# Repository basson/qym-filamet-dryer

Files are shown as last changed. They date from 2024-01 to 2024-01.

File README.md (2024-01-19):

# qym-filamnet-dryer

DIY filament dryer

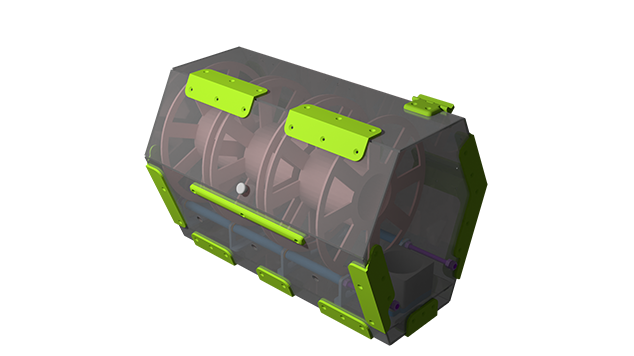
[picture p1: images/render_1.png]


Сушилка на 3 катушки, с возможностью печатать сразу из сушилки.

Помещаться должны самые большие катушки размеры которых я нашел.

Максимальная ширина катушки 98мм максимальный диаметр катушки 215мм.

Проект находится в стадии разработки.

Вся разработка ведётся на стримах.

Следить за проектом можно на моем канале YouTube:

https://www.youtube.com/playlist?list=PLECrWHz_TG886tEzgreLgq92PoEziWuON

# Планируемый функционал:

* Контроль температуры и влажности.
* Таймеры для сушки.
* Разные алгоритмы сушики пластика.
* Интеграция в klipper для управления из него.
* Для владельцев Flying Bear GHost 6 есть возможность установки сушилки вторым этажом прям на колпак принтера. (Колпак пилится одновременно с сушилкой и скоро тоже появится у меняв репозиториях)

---

**Что имеем сейчас:**

В папках stl, cad, draft чертежи для раскроя панелей на CO2 лазере, модели для печатных деталей и step фалы если кто-то решит что, то поправить.

Что будем делать на стримах:

* Проектировать плату в Kicad (схема уже накидана).
* Писать прошивку для управления сушилкой.
* Делать интеграцию в Klipper.
* Печать всех деталей для новой версии сборка и тесты сушилки.

---

**Подписывайся на мой youtube канал я там стараюсь вести регулярные стримы по всем своим проектам!!**

YouTube Transalations - https://www.youtube.com/@basson_xvi/streams

Thingiverse - https://www.thingiverse.com/thing:6427349

Printables - https://www.printables.com/model/716319-flying-bear-ghost-6-slim-skirt-for-electronics-pla

(https://www.buymeacoffee.com/basson)

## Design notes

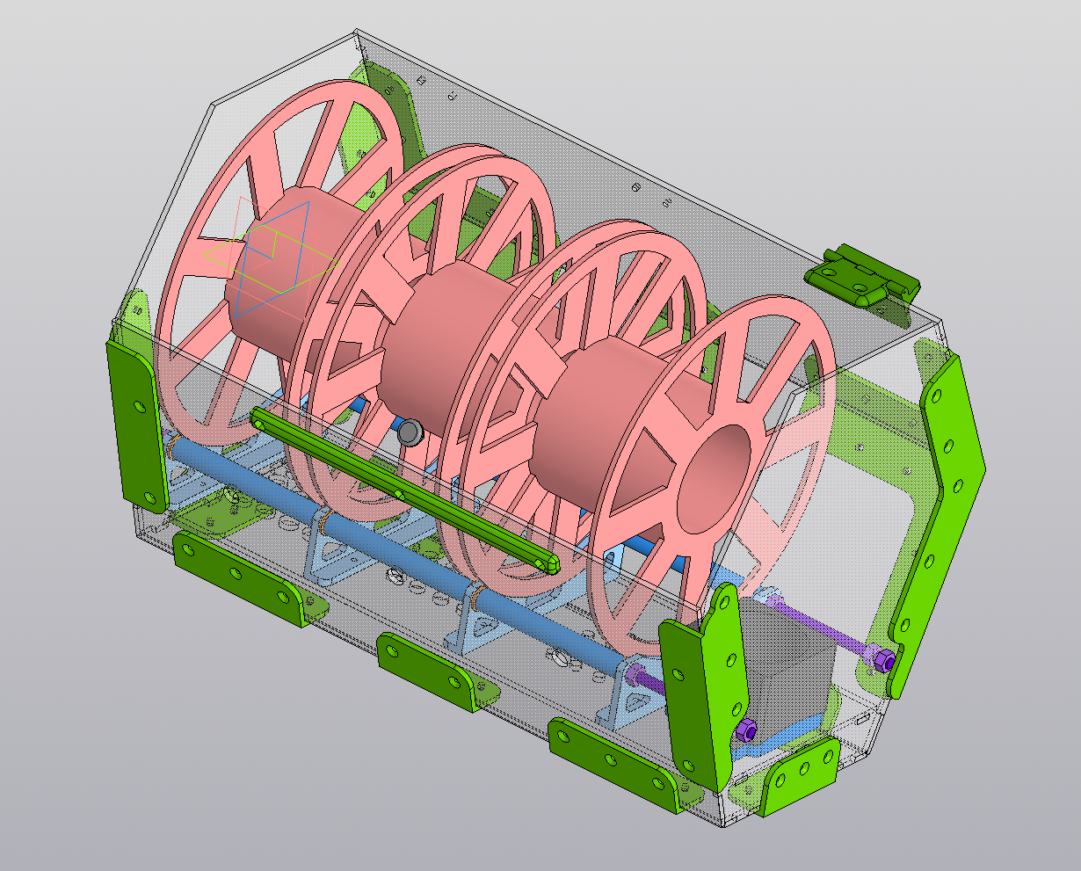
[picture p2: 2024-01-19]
images/screen_2.png

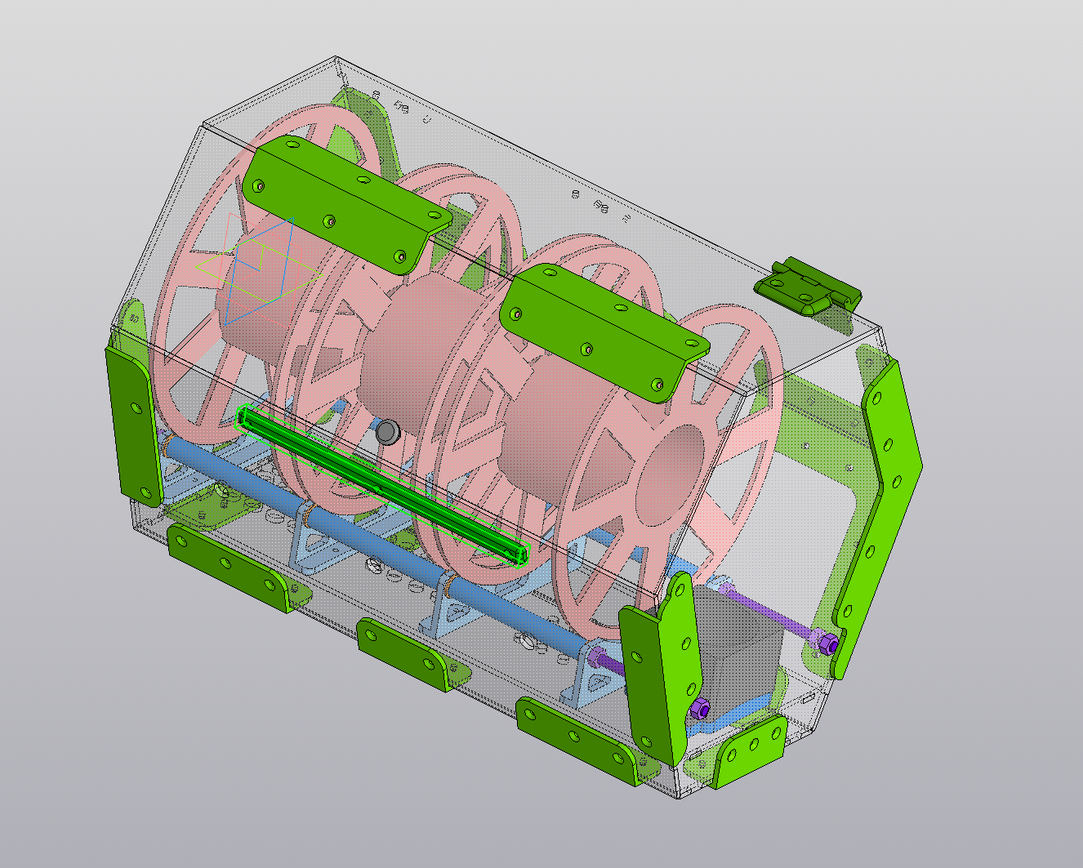
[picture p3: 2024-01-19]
images/screen_1.png

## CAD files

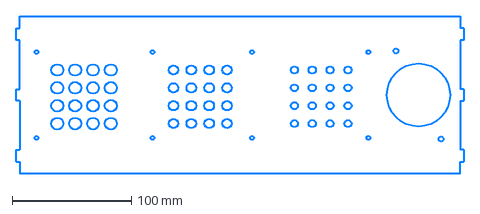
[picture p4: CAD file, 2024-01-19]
draft/holder_floor.dxf
376.0 x 132.0 mm

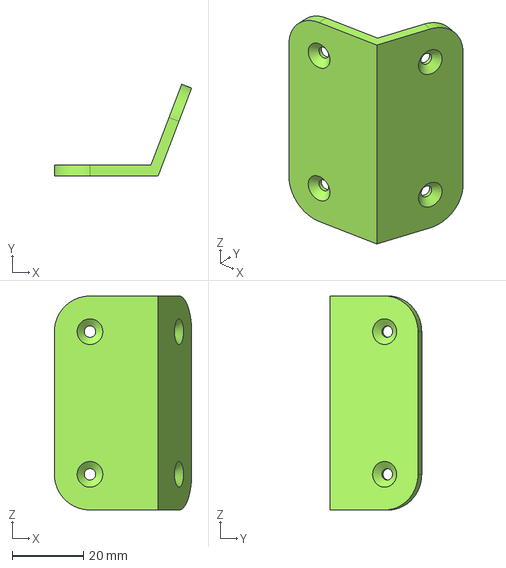
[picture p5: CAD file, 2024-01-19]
cad/Corner_bottom_front_centered.stp
38.5 x 25.7 x 60.0 mm

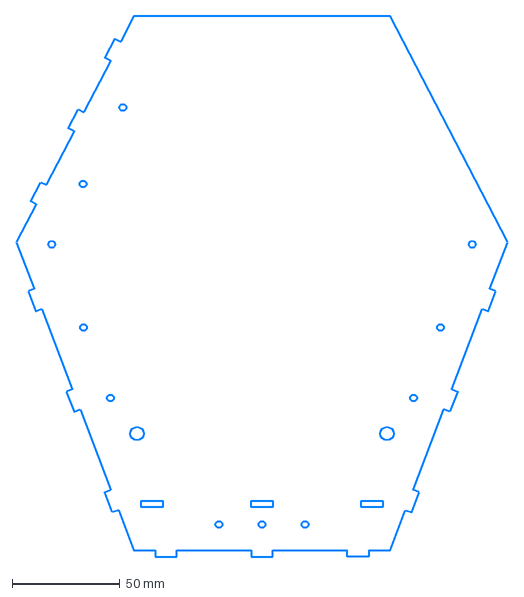
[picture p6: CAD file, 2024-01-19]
draft/side_wall.dxf
228.0 x 251.0 mm

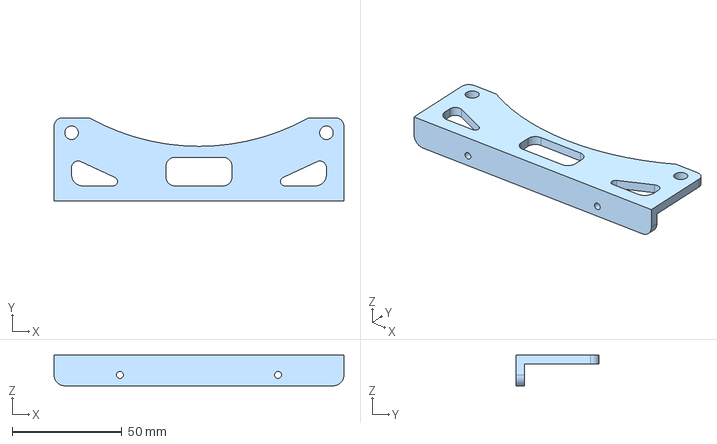
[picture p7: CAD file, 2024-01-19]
cad/holder.stp
132.0 x 38.0 x 14.0 mm

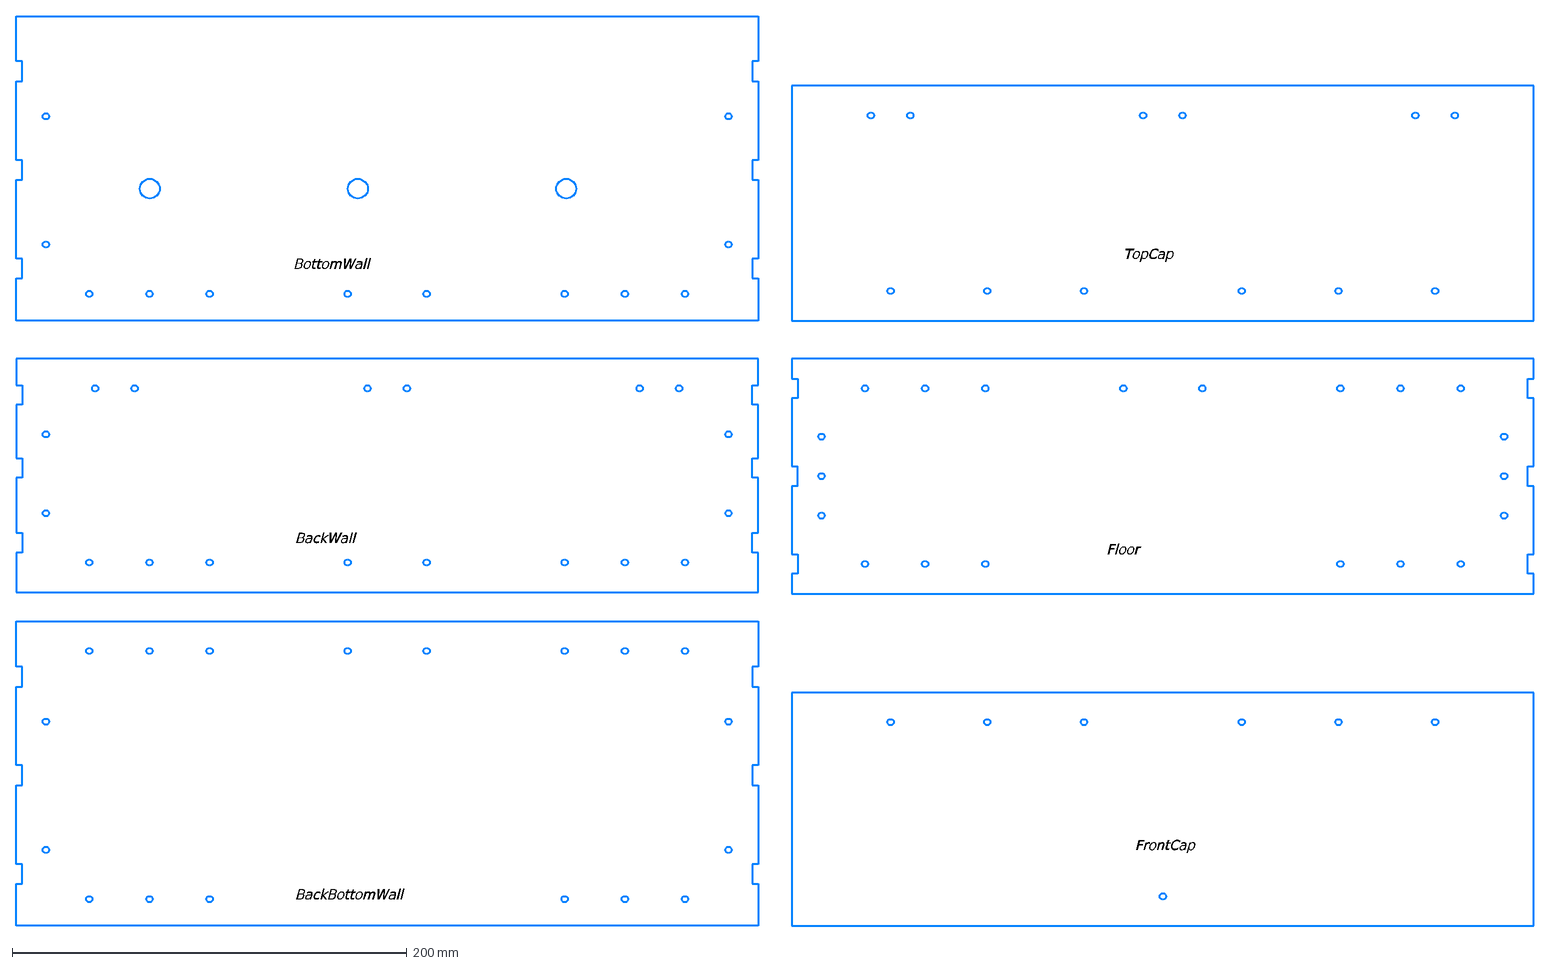
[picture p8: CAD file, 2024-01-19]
draft/all_walls.dxf
BackBottomWall
BackWall
BottomWall
Floor
FrontCap
TopCap

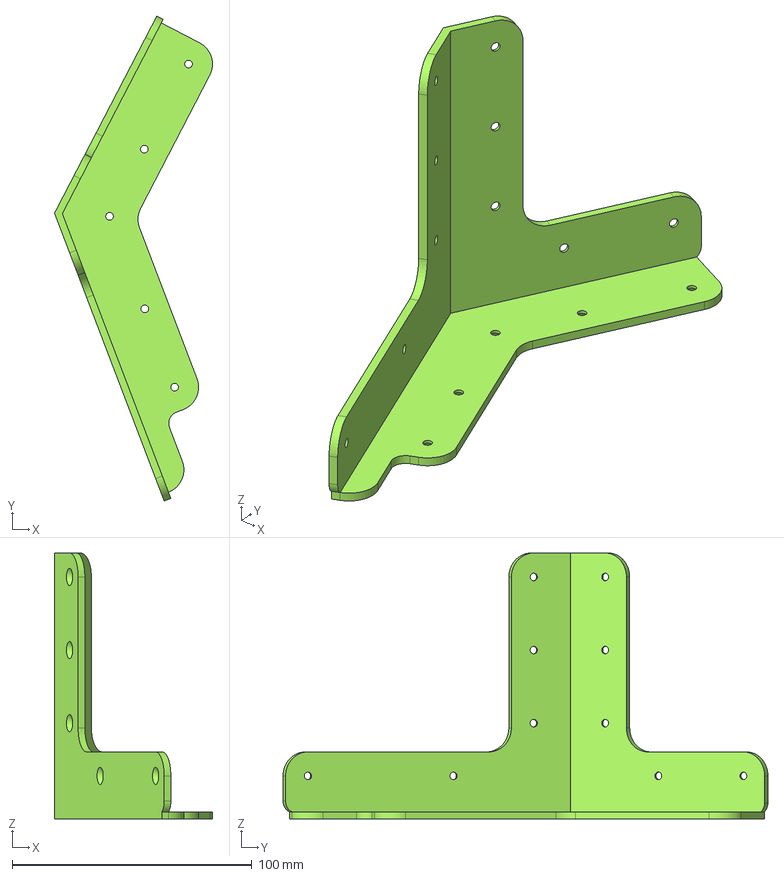
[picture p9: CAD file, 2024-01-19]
cad/Corner_back_side.stp
66.0 x 202.4 x 111.0 mm

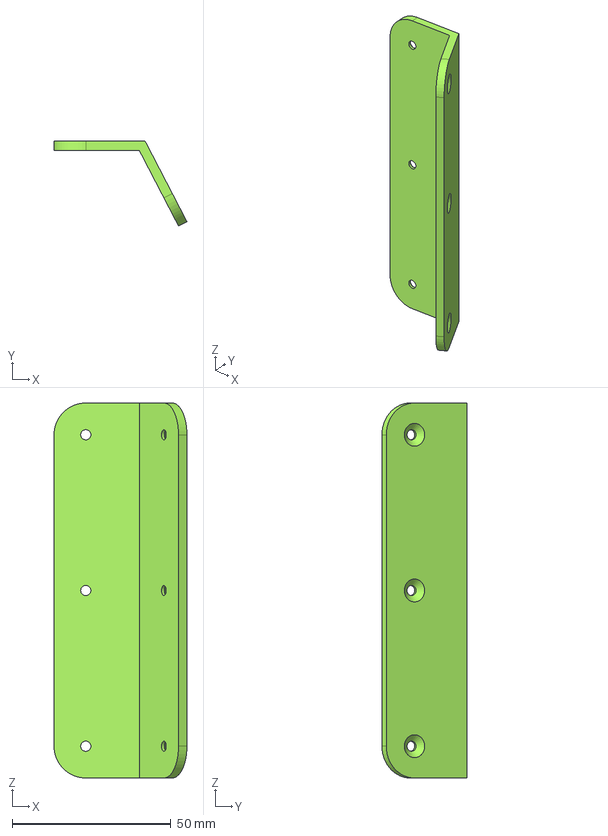
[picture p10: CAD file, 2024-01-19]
cad/Corner_cap.stp
41.8 x 26.8 x 118.0 mm

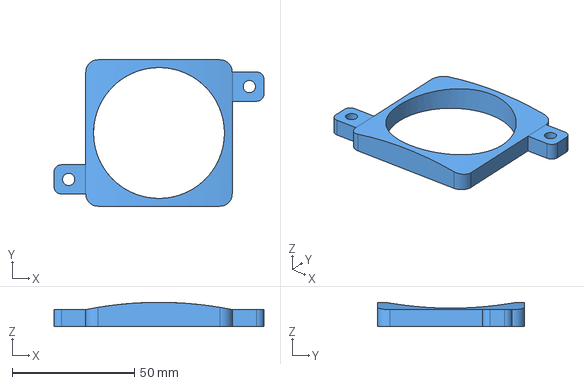
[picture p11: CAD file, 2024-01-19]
cad/Air_Conductor_2.stp
86.0 x 60.0 x 10.00 mm

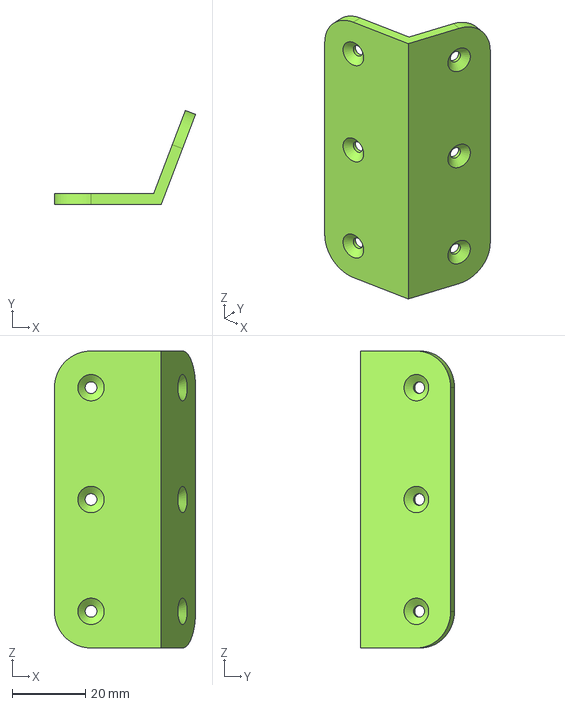
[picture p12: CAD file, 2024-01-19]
cad/Corner_bottop_front.stp
38.5 x 25.7 x 81.0 mm

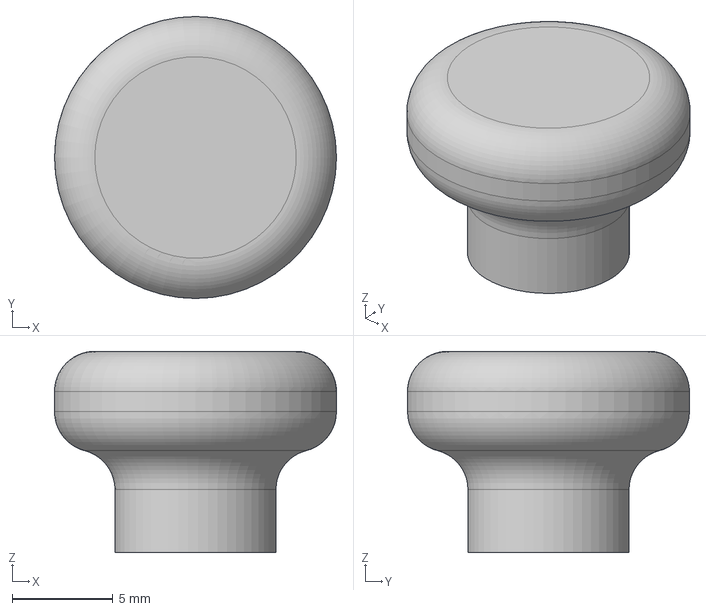
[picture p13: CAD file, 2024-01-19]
cad/Ruchka.stp
14.0 x 14.0 x 10.0 mm

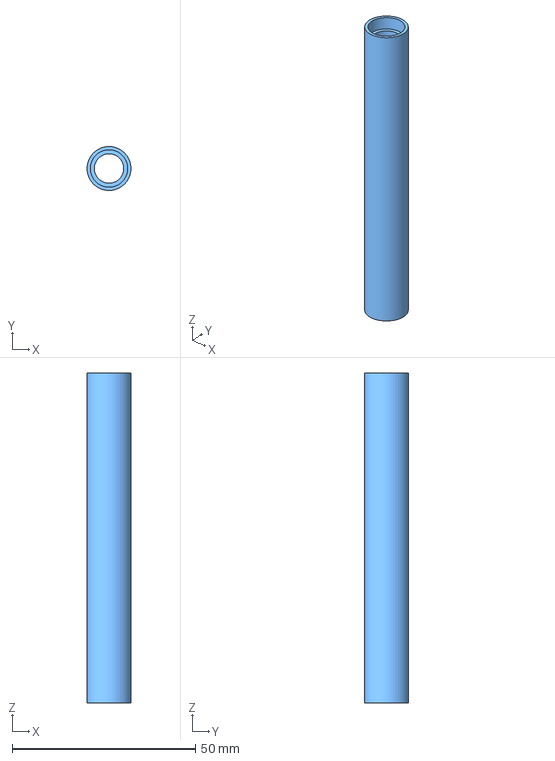
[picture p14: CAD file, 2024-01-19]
cad/roller.stp
12.0 x 12.0 x 90.0 mm

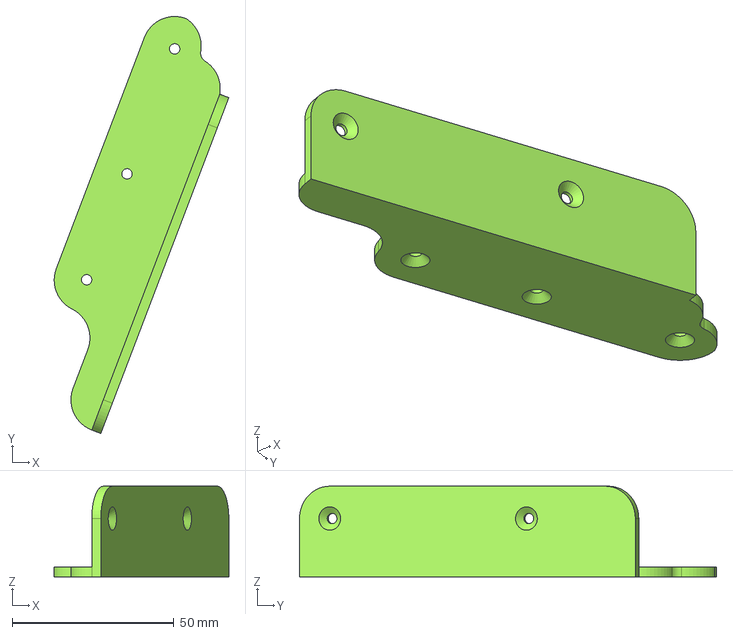
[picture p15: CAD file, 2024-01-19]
cad/Corner_front_side.stp
53.9 x 128.8 x 28.0 mm

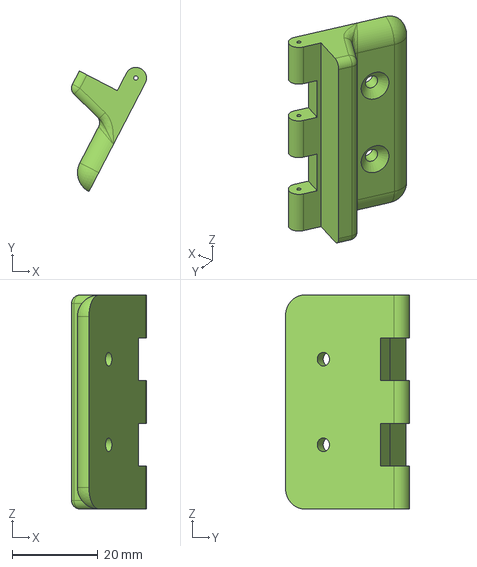
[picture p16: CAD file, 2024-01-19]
cad/Hinge_wall.stp
17.6 x 29.0 x 50.0 mm

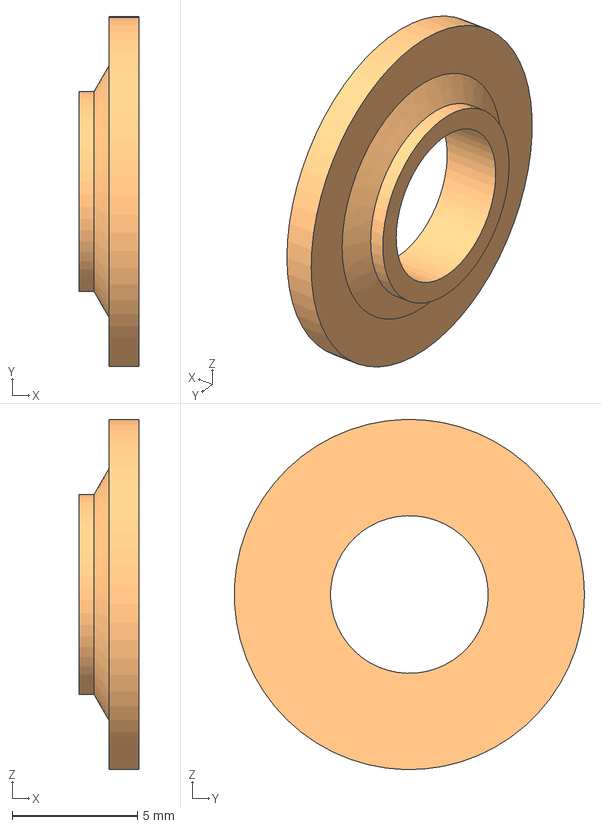
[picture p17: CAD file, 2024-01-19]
cad/Spacer_D14x8x6.3_W2.4.stp
2.40 x 14.0 x 14.0 mm

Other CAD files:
cad/dry.stp
cad/Streang_Beam_Bottom.stp
cad/Hinge_cover.stp
cad/Corner_back_centered.stp
cad/Corner_bottom_side.stp
cad/fitting_nut.stp
stl/Air_Conductor_2.stl
stl/Corner_back_centered.stl
stl/Corner_back_side.stl
stl/Corner_bottom_front_centered.stl
stl/Corner_bottom_side.stl
stl/Corner_bottop_front.stl
stl/Corner_cap.stl
stl/Corner_front_side.stl
stl/Hinge_cover.stl
stl/Hinge_wall.stl
stl/Ruchka.stl
stl/Spacer_D14x8x6.3_W2.4.stl
stl/Streang_Beam_Bottom.stl
stl/fitting_nut.stl
stl/holder.stl
stl/roller.stl

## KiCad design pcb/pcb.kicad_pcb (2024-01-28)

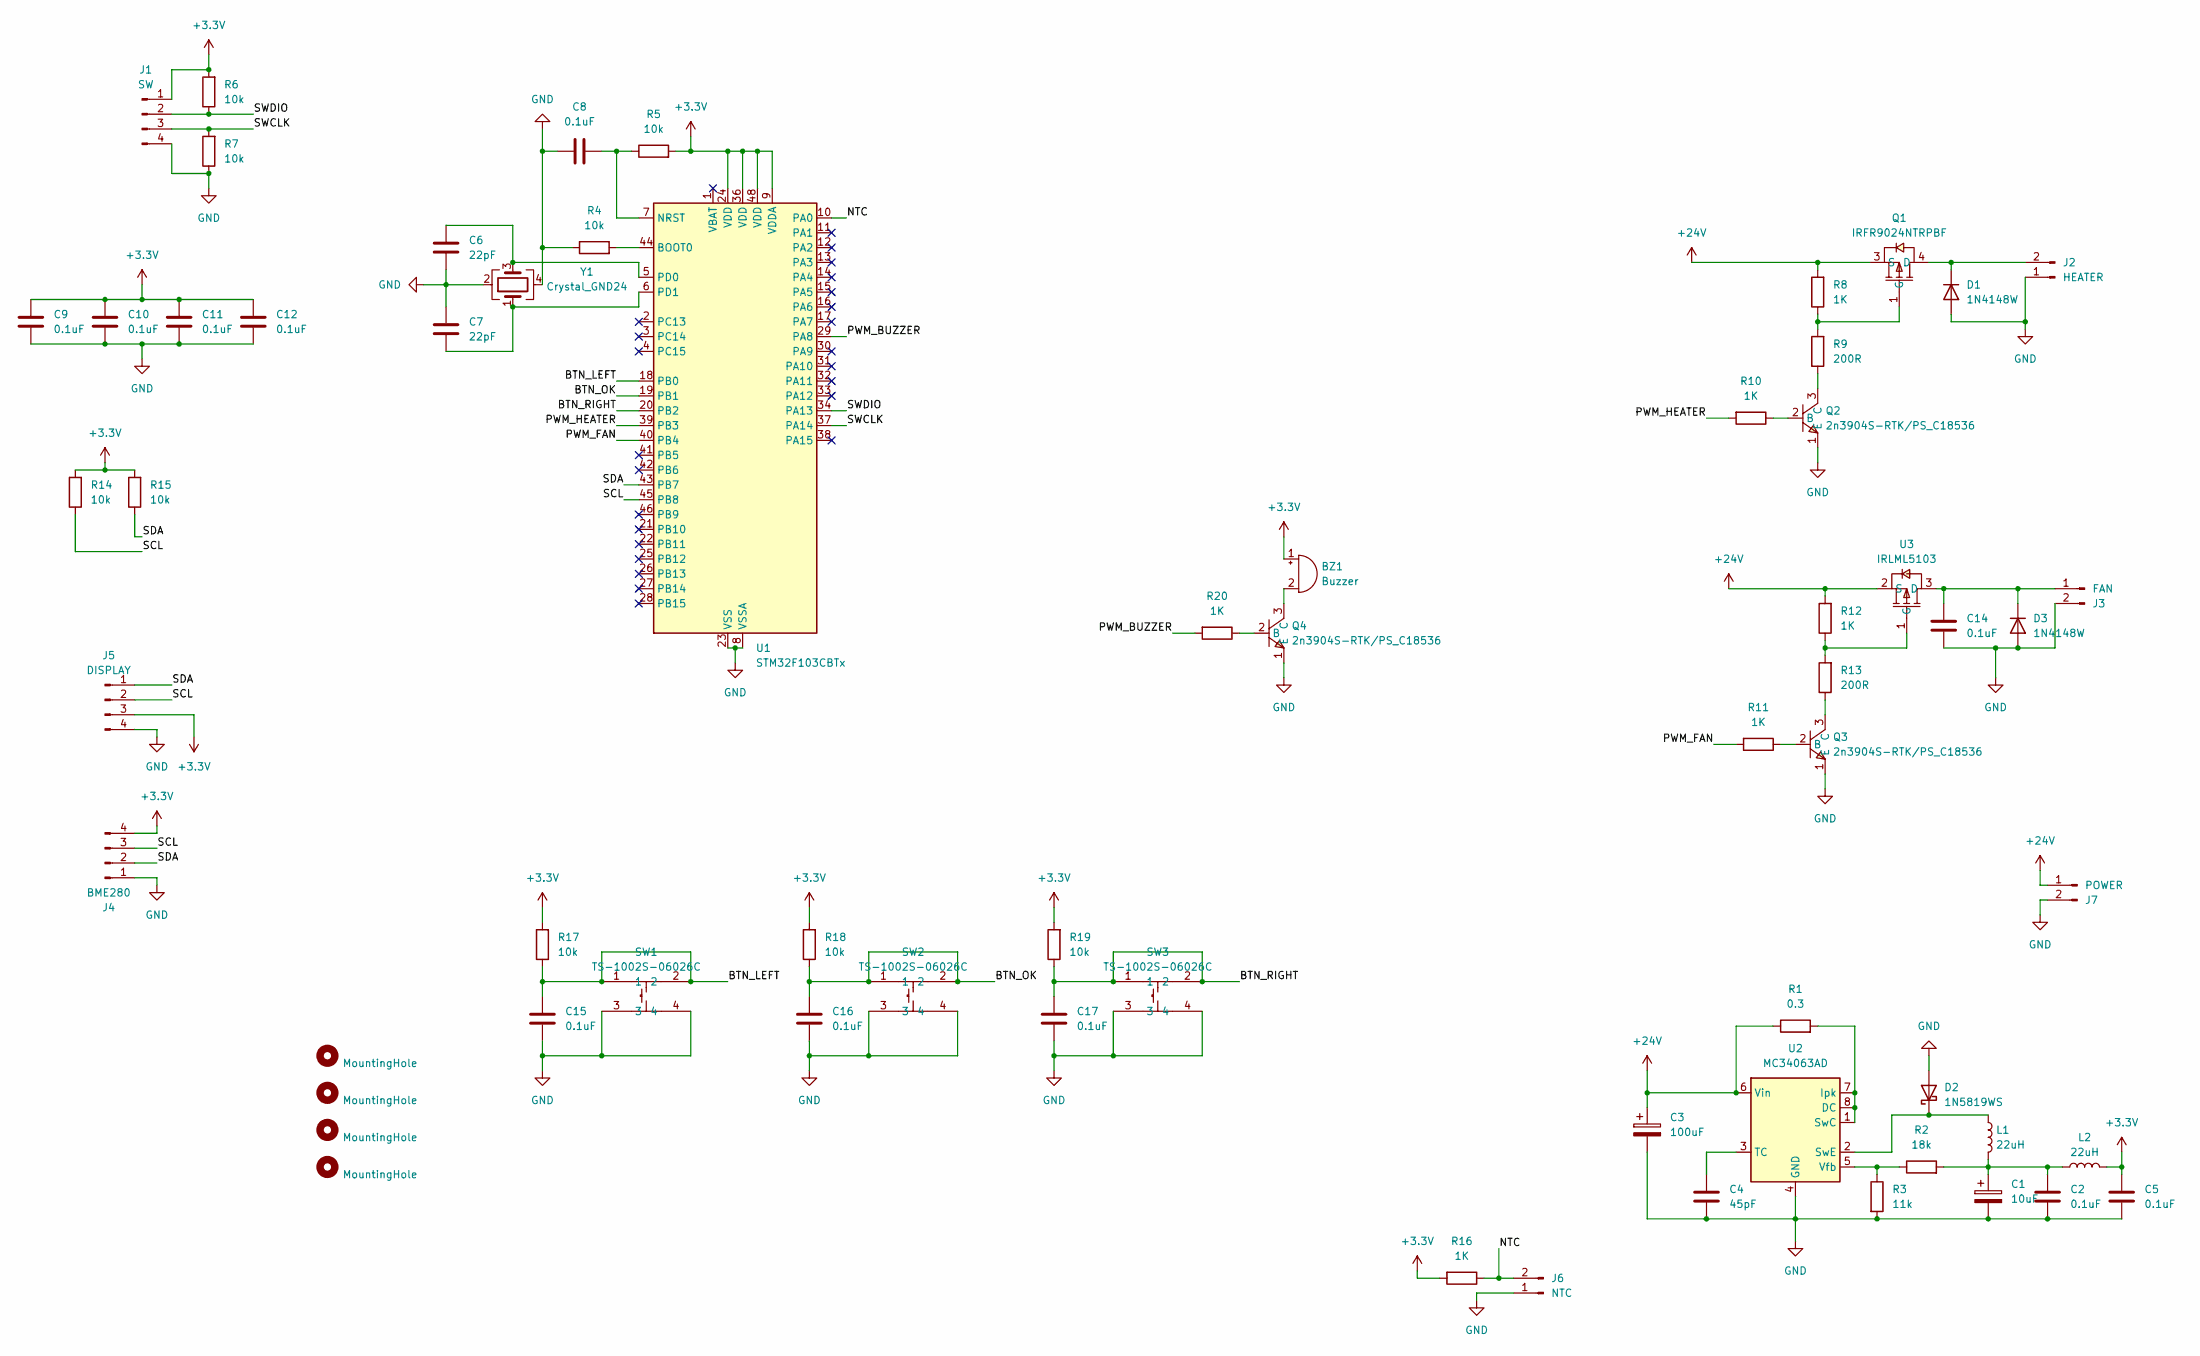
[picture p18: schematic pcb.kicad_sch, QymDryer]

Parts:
BZ1: Buzzer; Buzzer_12x9.5RM7.6
C1: 10uF; CP_Radial_D5.0mm_P2.50mm
C2, C5, C8, C9, C10, C11, C12, C14, C15, C16, C17: 0.1uF; C_1206_3216Metric_Pad1.33x1.80mm_HandSolder
C3: 100uF; CP_Radial_D8.0mm_P5.00mm
C4: 45pF; C_1206_3216Metric_Pad1.33x1.80mm_HandSolder
C6, C7: 22pF; C_1206_3216Metric_Pad1.33x1.80mm_HandSolder
D1, D3: 1N4148W; D_SOD-123
D2: 1N5819WS; D_2114_3652Metric_Pad1.85x3.75mm_HandSolder
H1, H2, H3, H4: MountingHole; MountingHole_3.2mm_M3_DIN965_Pad
J1: SW; PinHeader_1x04_P2.54mm_Vertical
J2: HEATER; TerminalBlock_Phoenix_MKDS-1,5-2_1x02_P5.00mm_Horizontal
J3: FAN; CONN-TH_2P-P2.50_HC-XH-2A-G
J4: BME280; CONN-TH_4P-P2.50_HC-XH-4A-G
J5: DISPLAY; Display_128x64_096_I2C
J6: NTC; CONN-TH_2P-P2.50_HC-XH-2A-G
J7: POWER; TerminalBlock_Phoenix_MKDS-1,5-2_1x02_P5.00mm_Horizontal
L1: 22uH; L_6.3x6.3_H3
L2: 22uH; L_1206_3216Metric_Pad1.22x1.90mm_HandSolder
Q1: IRFR9024NTRPBF; TO-252-2_L6.6-W6.1-P4.58-LS9.9-TR; LCSC Part C2585
Q2, Q3, Q4: 2n3904S-RTK/PS_C18536; SOT-23-3_L2.9-W1.3-P1.90-LS2.4-TR; LCSC Part C18536
R1: 0.3; R_1206_3216Metric_Pad1.30x1.75mm_HandSolder
R2: 18k; R_1206_3216Metric_Pad1.30x1.75mm_HandSolder
R3: 11k; R_1206_3216Metric_Pad1.30x1.75mm_HandSolder
R4, R5, R6, R7, R14, R15, R17, R18, R19: 10k; R_1206_3216Metric_Pad1.30x1.75mm_HandSolder
R8, R10, R11, R12, R16, R20: 1K; R_1206_3216Metric_Pad1.30x1.75mm_HandSolder
R9, R13: 200R; R_1206_3216Metric_Pad1.30x1.75mm_HandSolder
SW1, SW2, SW3: TS-1002S-06026C; KEY-SMD_4P-L6.0-W6.0-P4.50-LS9.5-BR; LCSC Part C455112
U1: STM32F103CBTx; LQFP-48_7x7mm_P0.5mm
U2: MC34063AD; SOIC-8_3.9x4.9mm_P1.27mm
U3: IRLML5103; SOT-23-3_L3.0-W1.7-P0.95-LS2.9-BR; LCSC Part C5364309
Y1: Crystal_GND24; Crystal_SMD_5032-4Pin_5.0x3.2mm

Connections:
+3.3V: BZ1.1 (-), C5.1, C9.2, C10.2, C11.2, C12.2, J1.1, J4.4, J5.3, L2.2, R5.2, R6.2, R14.2, R15.2, R16.2, R17.2, R18.2, R19.2, U1.9 (VDDA), U1.24 (VDD), U1.36 (VDD), U1.48 (VDD)
+24V: C3.1, J7.1, Q1.3 (S), R1.1, R8.2, R12.2, U2.6 (Vin), U3.2 (S)
/BTN_LEFT: C15.2, R17.1, SW1.1, SW1.2, U1.18 (PB0)
/BTN_OK: C16.2, R18.1, SW2.1, SW2.2, U1.19 (PB1)
/BTN_RIGHT: C17.2, R19.1, SW3.1, SW3.2, U1.20 (PB2)
/NTC: J6.2, R16.1, U1.10 (PA0)
/PWM_BUZZER: R20.2, U1.29 (PA8)
/PWM_FAN: R11.2, U1.40 (PB4)
/PWM_HEATER: R10.2, U1.39 (PB3)
/SCL: J4.3, J5.2, R14.1, U1.45 (PB8)
/SDA: J4.2, J5.1, R15.1, U1.43 (PB7)
/SWCLK: J1.3, R7.2, U1.37 (PA14)
/SWDIO: J1.2, R6.1, U1.34 (PA13)
GND: C1.2, C2.2, C3.2, C4.2, C5.2, C6.1, C7.1, C8.1, C9.1, C10.1, C11.1, C12.1, C14.2, C15.1, C16.1, C17.1, D1.2 (A), D2.2 (A), D3.2 (A), J1.4, J2.1, J3.2, J4.1, J5.4, J6.1, J7.2, Q2.1 (E), Q3.1 (E), Q4.1 (E), R3.2, R4.1, R7.1, SW1.3, SW1.4, SW2.3, SW2.4, SW3.3, SW3.4, U1.8 (VSSA), U1.23 (VSS), U1.35 (VSS), U1.47 (VSS), U2.4 (GND), Y1.2, Y1.4
unnamed: BZ1.2 (+), Q4.3 (C)
unnamed: C1.1, C2.1, L1.2, L2.1, R2.2
unnamed: D1.1 (K), J2.2, Q1.4 (D)
unnamed: D2.1 (K), L1.1, U2.2 (SwE)
unnamed: C14.1, D3.1 (K), J3.1, U3.3 (D)
unnamed: Q1.1 (G), R8.1, R9.2
unnamed: Q2.2 (B), R10.1
unnamed: Q2.3 (C), R9.1
unnamed: Q3.2 (B), R11.1
unnamed: Q3.3 (C), R13.1
unnamed: Q4.2 (B), R20.1
unnamed: R4.2, U1.44 (BOOT0)
unnamed: C8.2, R5.1, U1.7 (NRST)
unnamed: C6.2, U1.5 (PD0), Y1.3
unnamed: C7.2, U1.6 (PD1), Y1.1
unnamed: R1.2, U2.1 (SwC), U2.7 (Ipk), U2.8 (DC)
unnamed: C4.1, U2.3 (TC)
unnamed: R2.1, R3.1, U2.5 (Vfb)
unnamed: R12.1, R13.2, U3.1 (G)

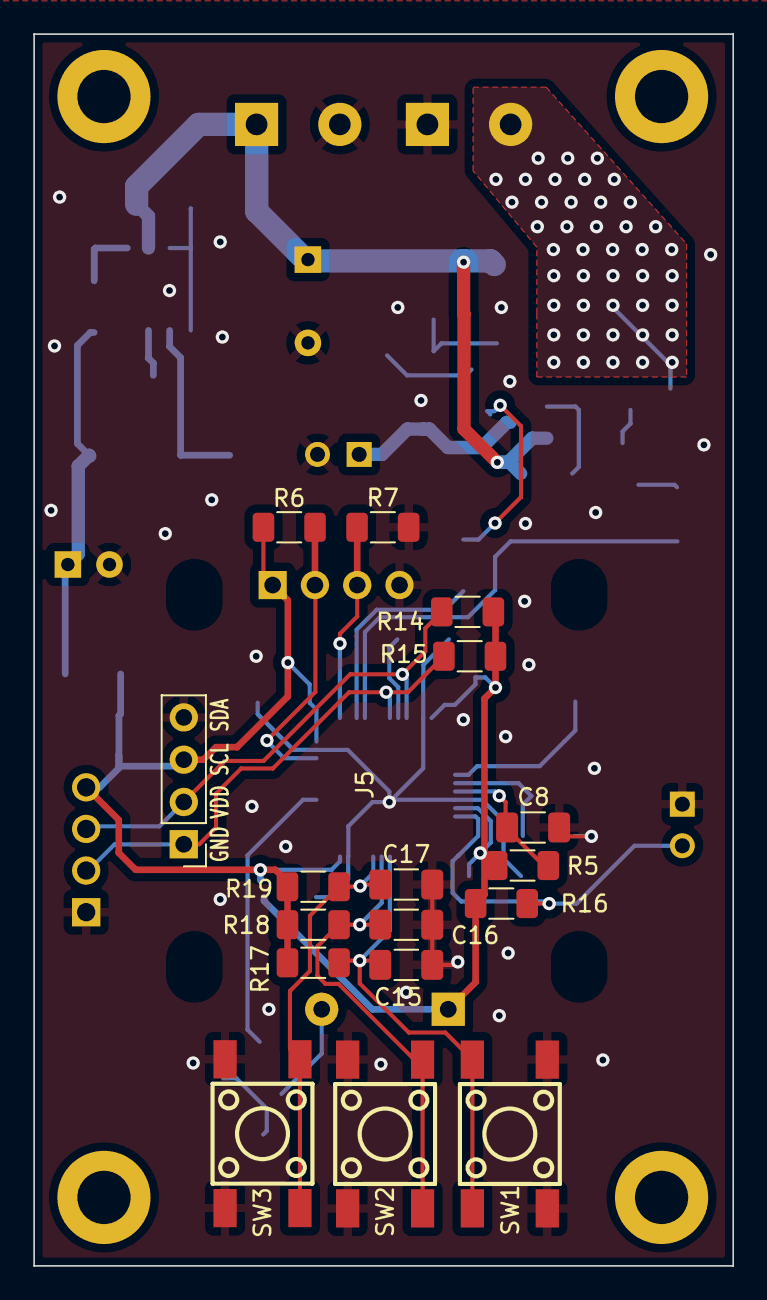
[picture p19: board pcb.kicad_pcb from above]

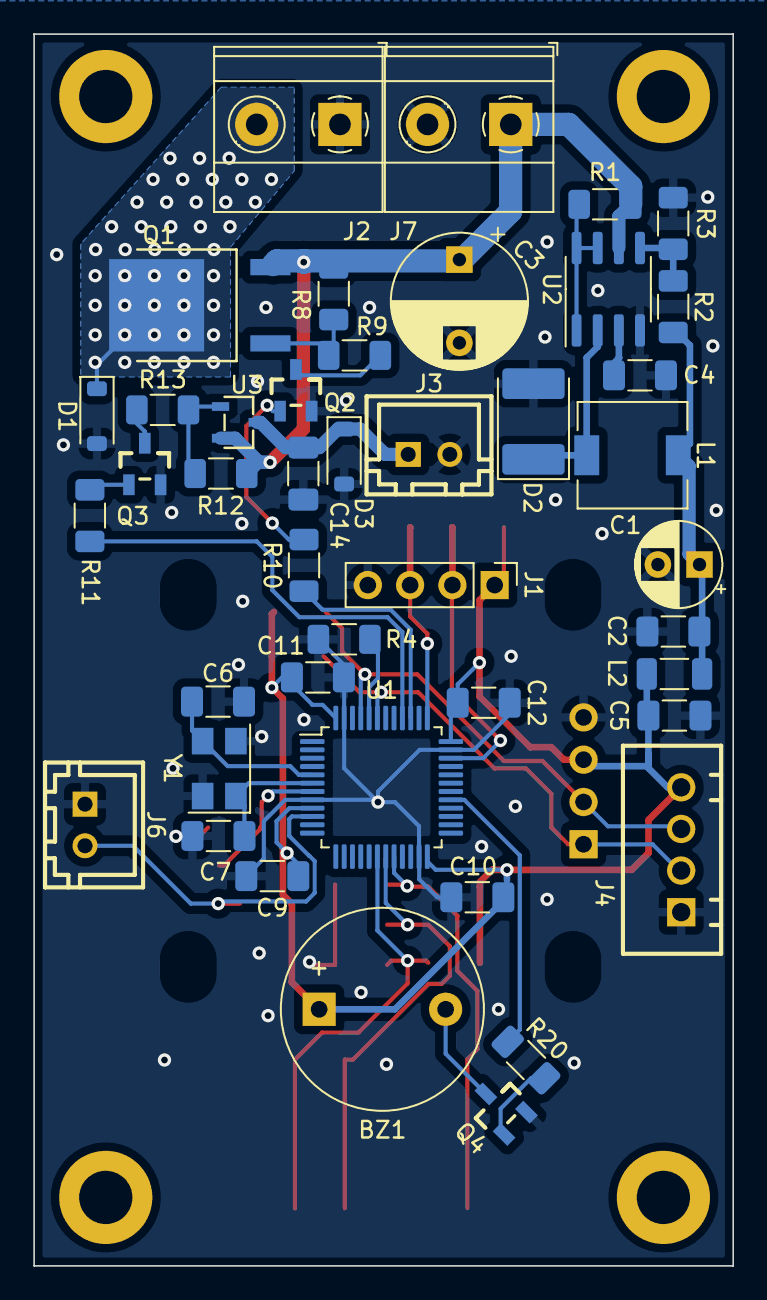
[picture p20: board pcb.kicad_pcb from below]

Board: 2 copper layers, 42.0 x 74.0 mm, 64 parts (43 on the bottom side), 33 nets.

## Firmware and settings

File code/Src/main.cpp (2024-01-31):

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
/* Includes ------------------------------------------------------------------*/
#include "main.h"
#include "adc.h"
#include "i2c.h"
#include "tim.h"
#include "gpio.h"


void SystemClock_Config(void);
/**
  * @brief  The application entry point.
  * @retval int
  */
int main(void)
{
  /* MCU Configuration--------------------------------------------------------*/

  /* Reset of all peripherals, Initializes the Flash interface and the Systick. */
  HAL_Init();

  /* Configure the system clock */
  SystemClock_Config();

  /* Initialize all configured peripherals */
  MX_GPIO_Init();
  MX_ADC1_Init();
  MX_I2C1_Init();
  MX_TIM1_Init();
  MX_TIM2_Init();
  MX_TIM3_Init();
  /* Infinite loop */
  /* USER CODE BEGIN WHILE */
  while (1)
  {
    /* USER CODE END WHILE */

    /* USER CODE BEGIN 3 */
  }
  /* USER CODE END 3 */
}

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


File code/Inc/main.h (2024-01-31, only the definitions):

#define NTC_Pin GPIO_PIN_0
#define NTC_GPIO_Port GPIOA
#define BTN_LFET_Pin GPIO_PIN_0
#define BTN_LFET_GPIO_Port GPIOB
#define BTN_OK_Pin GPIO_PIN_1
#define BTN_OK_GPIO_Port GPIOB
#define BTN_RIGHT_Pin GPIO_PIN_2
#define BTN_RIGHT_GPIO_Port GPIOB
#define PWM_BUZZER_Pin GPIO_PIN_8
#define PWM_BUZZER_GPIO_Port GPIOA
#define PWM_HEATER_Pin GPIO_PIN_3
#define PWM_HEATER_GPIO_Port GPIOB
#define PWM_FAN_Pin GPIO_PIN_4
#define PWM_FAN_GPIO_Port GPIOB
#define SCL_Pin GPIO_PIN_6
#define SCL_GPIO_Port GPIOB
#define SDA_Pin GPIO_PIN_7
#define SDA_GPIO_Port GPIOB

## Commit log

2024-01-19 Все наработки по сушлке на данный момент.
    [Air_Conductor_2.stl, Air_Conductor_2.stp, Corner_back_centered.stl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]
2024-01-21 Work with schematics and pcb. update *.ioc files at project.
    [pcb.kicad_pcb, pcb.kicad_sch]
2024-01-27 Work in pcb placment components
    [pcb.kicad_pcb]
2024-01-28 Update display ss1306 footprint. paste text refrenece on pcb
    [pcb.kicad_pcb, pcb.kicad_sch]
2024-01-31 Add fitting nut and initalize code from control board firmware
    [fitting_nut.stl, fitting_nut.stp]

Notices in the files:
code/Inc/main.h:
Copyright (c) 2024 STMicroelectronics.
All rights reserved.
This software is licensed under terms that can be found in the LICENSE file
